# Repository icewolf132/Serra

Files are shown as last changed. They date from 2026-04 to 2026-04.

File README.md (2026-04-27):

# Serra domotica

Sistema di controllo automatizzato per la gestione di una serra che segue la [traccia della Gara Nazionale di Elettronica del 2023](https://github.com/icewolf132/Serra/blob/main/documentazione/2023%20Traccia%20GnE%202023.pdf).

---

## Contenuti del repository

* `schemi/` – schemi elettrici, PCB e partlist
* `firmware/` – codice sorgente per i microcontrollori PIC
* `documentazione/` – documentazione

---

## Diagramma 

[diagramma_progetto](https://github.com/icewolf132/Serra/blob/main/documentazione/foto/diagramma_progetto.png)

---

### Autore del progetto

* William Landolfi

---

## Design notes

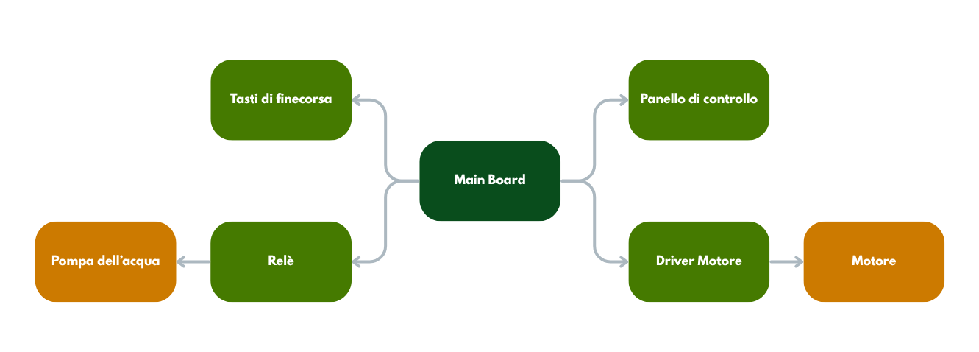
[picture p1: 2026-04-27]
documentazione/foto/diagramma_progetto.png

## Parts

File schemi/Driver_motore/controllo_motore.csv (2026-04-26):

Reference | Qty | Value | DNP | Exclude from BOM | Exclude from Board | Footprint | Datasheet
C1,C3 | 2 | 100nF |  |  |  |  | ~
C2 | 1 | 0,22uF |  |  |  |  | ~
C4 | 1 | 0,1uF |  |  |  |  | ~
D1 | 1 | 1N4007 |  |  |  | Diode_THT:D_DO-41_SOD81_P10.16mm_Horizontal | http://www.vishay.com/docs/88503/1n4001.pdf
J1 | 1 | PICKIT |  |  |  | Connector_PinSocket_2.54mm:PinSocket_1x06_P2.54mm_Vertical | ~
J2 | 1 | Motore |  |  |  | Connector_PinSocket_2.54mm:PinSocket_1x06_P2.54mm_Vertical | ~
J3 | 1 | Power |  |  |  | TerminalBlock:TerminalBlock_MaiXu_MX126-5.0-02P_1x02_P5.00mm | ~
J4 | 1 | Conn |  |  |  | Connector_PinSocket_2.54mm:PinSocket_1x05_P2.54mm_Vertical | ~
R4,R5,R6 | 3 | 470 |  |  |  |  | ~
U1 | 1 | L298N |  |  |  | Package_TO_SOT_THT:TO-220-15_P2.54x5.08mm_StaggerOdd_Lead4.58mm_Vertical | http://www.st.com/st-web-ui/static/active/en/resource/technical/document/datasheet/CD00000240.pdf
U2 | 1 | PIC16F88-IP |  |  |  | Package_DIP:DIP-18_W7.62mm_LongPads | http://ww1.microchip.com/downloads/en/DeviceDoc/30487D.pdf
U3 | 1 | LM7805_TO220 |  |  |  | Package_TO_SOT_THT:TO-220-3_Vertical | https://www.onsemi.cn/PowerSolutions/document/MC7800-D.PDF

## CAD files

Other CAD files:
firmware/driver_motore.X/dist/default/production/serra2.X.production.obj

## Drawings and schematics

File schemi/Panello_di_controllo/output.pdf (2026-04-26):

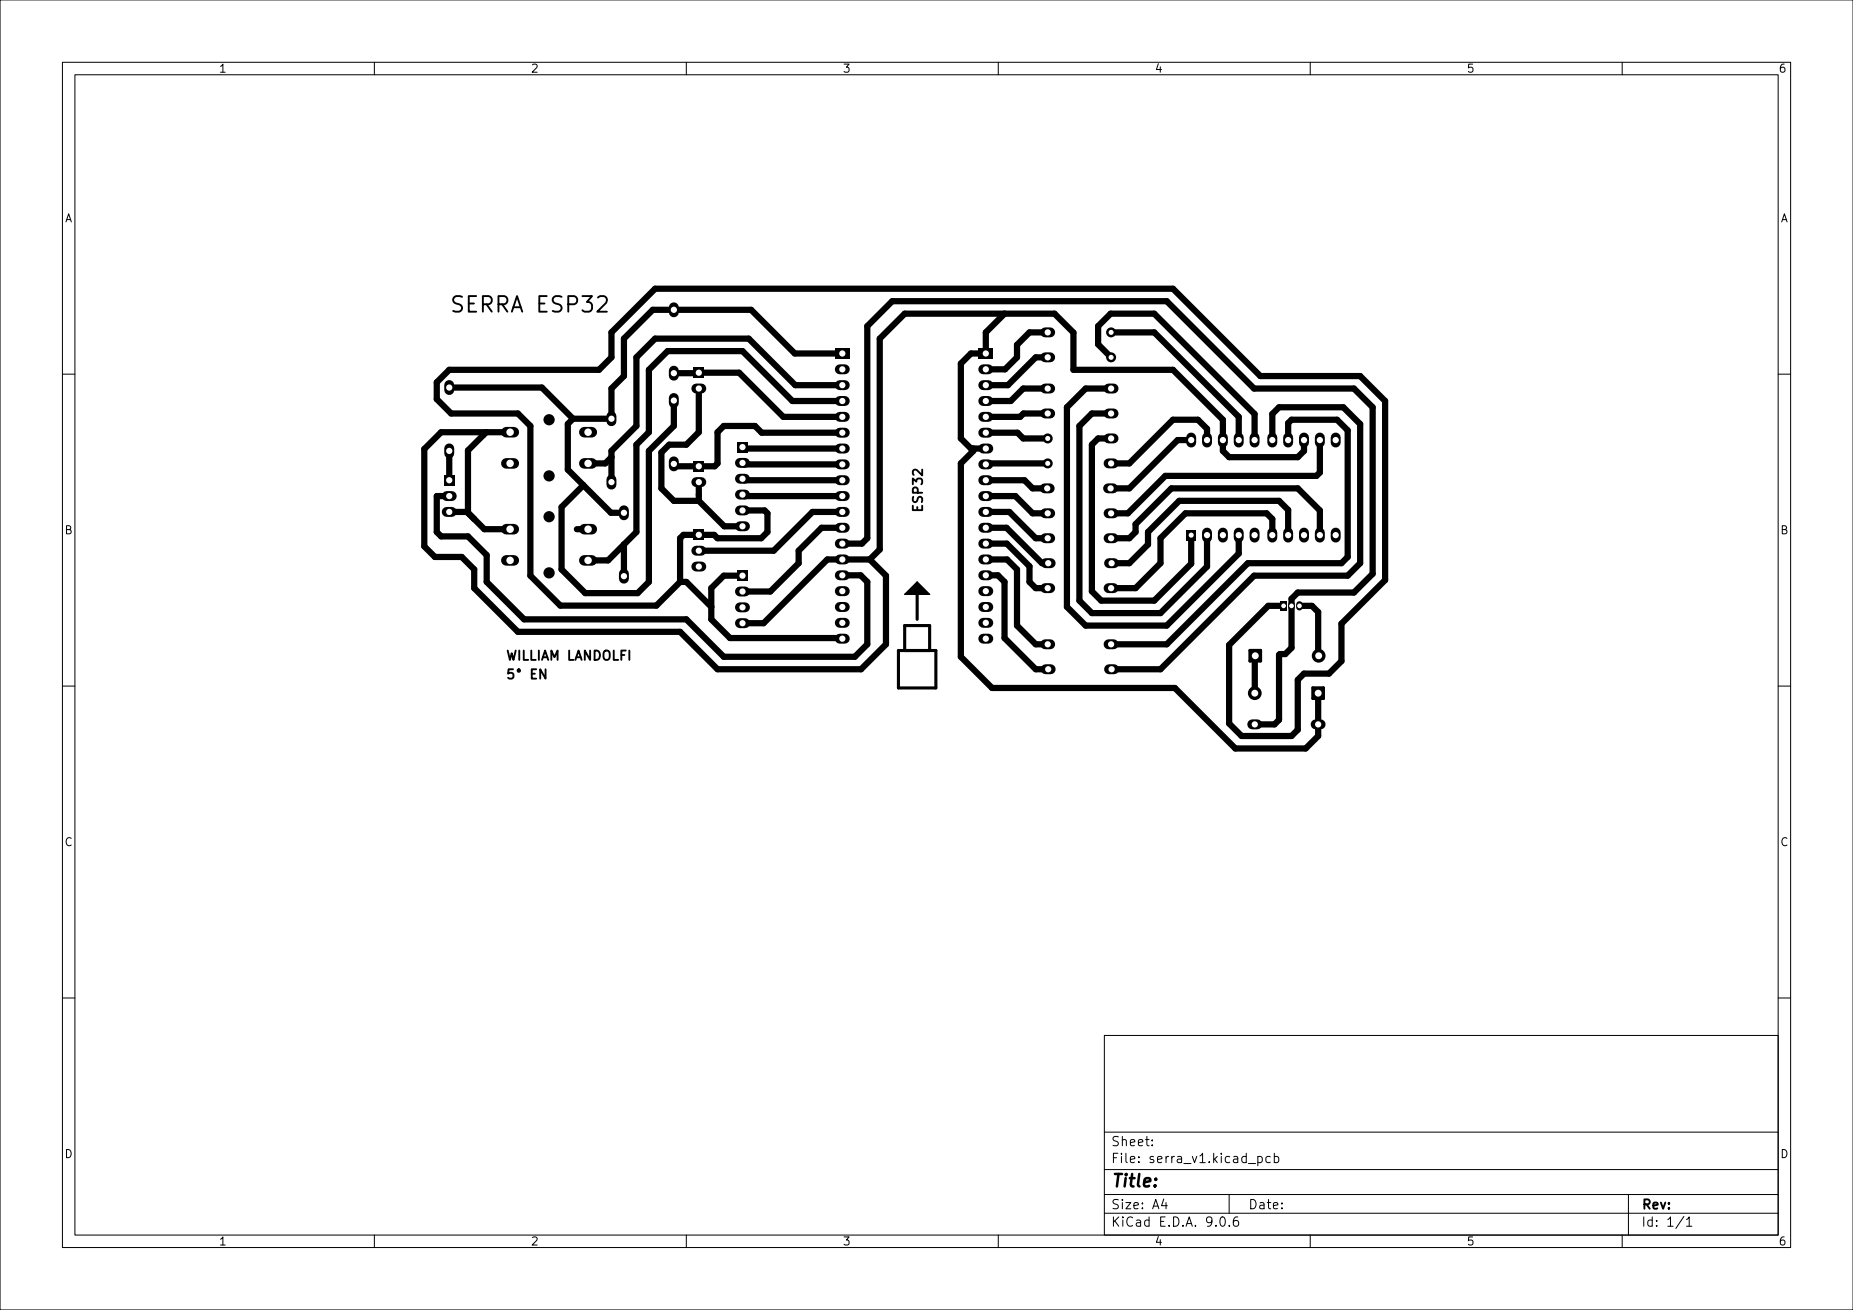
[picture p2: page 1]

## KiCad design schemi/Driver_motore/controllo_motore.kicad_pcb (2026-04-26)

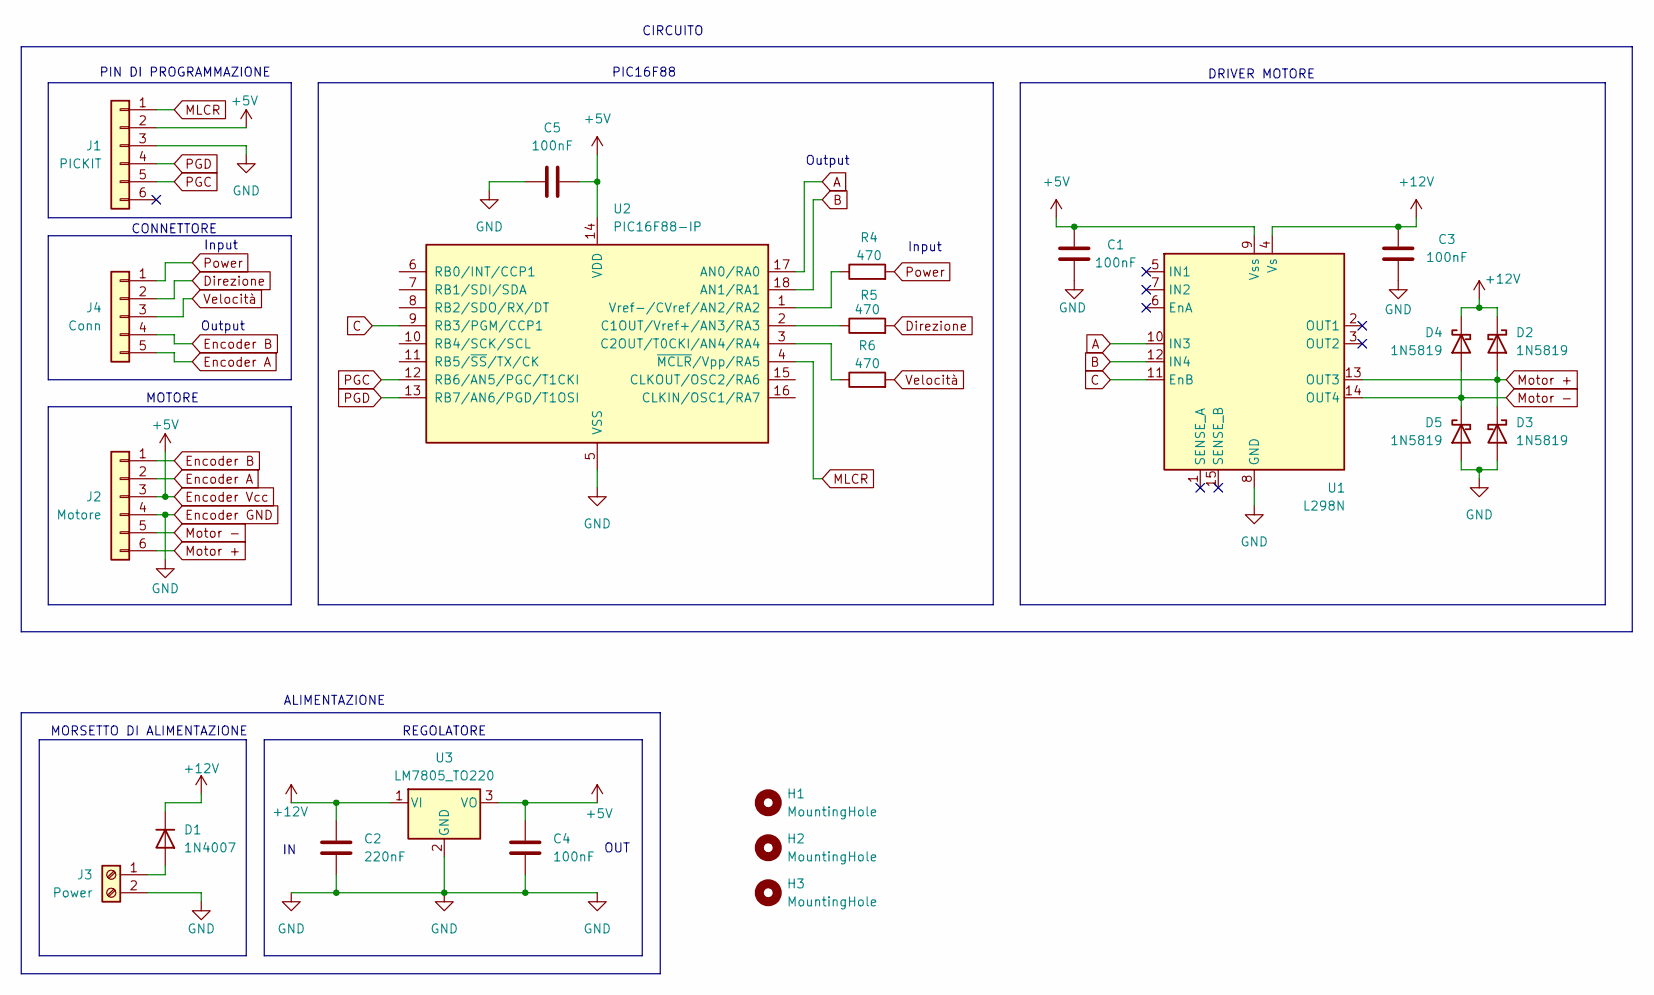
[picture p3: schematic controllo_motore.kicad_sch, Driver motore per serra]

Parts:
C1, C3, C4, C5: 100nF; C_Disc_D4.7mm_W2.5mm_P5.00mm
C2: 220nF; C_Disc_D4.7mm_W2.5mm_P5.00mm
D1: 1N4007; D_DO-41_SOD81_P10.16mm_Horizontal
D2, D3, D4, D5: 1N5819; D_DO-41_SOD81_P10.16mm_Horizontal
H1, H2, H3: MountingHole; MountingHole_3.2mm_M3_DIN965_Pad_TopBottom
J1: PICKIT; PinSocket_1x06_P2.54mm_Vertical
J2: Motore; PinSocket_1x06_P2.54mm_Vertical
J3: Power; TerminalBlock_MaiXu_MX126-5.0-02P_1x02_P5.00mm
J4: Conn; PinSocket_1x05_P2.54mm_Vertical
R4, R5, R6: 470; R_Axial_DIN0207_L6.3mm_D2.5mm_P10.16mm_Horizontal
U1: L298N; TO-220-15_P2.54x5.08mm_StaggerOdd_Lead4.58mm_Vertical
U2: PIC16F88-IP; DIP-18_W7.62mm_LongPads
U3: LM7805_TO220; TO-220-3_Vertical

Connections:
+12V: C2.1, C3.2, D1.1 (K), D2.1 (K), D4.1 (K), U1.4 (Vs), U3.1 (VI)
A: U1.10 (IN3), U2.17 (AN0/RA0)
B: U1.12 (IN4), U2.18 (AN1/RA1)
C: U1.11 (EnB), U2.9 (RB3/PGM/CCP1)
Direzione: J4.2, R5.2
Encoder A: J2.2, J4.5
Encoder B: J2.1, J4.4
Encoder GND: C1.1, C2.2, C3.1, C4.2, C5.1, D3.2 (A), D5.2 (A), J1.3, J2.4, J3.2, U1.8 (GND), U2.5 (VSS), U3.2 (GND)
Encoder Vcc: C1.2, C4.1, C5.2, J1.2, J2.3, U1.9 (Vss), U2.14 (VDD), U3.3 (VO)
MLCR: J1.1, U2.4 (~MCLR/Vpp/RA5)
Motor +: D2.2 (A), D3.1 (K), J2.6, U1.13 (OUT3)
Motor -: D4.2 (A), D5.1 (K), J2.5, U1.14 (OUT4)
unnamed: D1.2 (A), J3.1
unnamed: R5.1, U2.2 (C1OUT/Vref+/AN3/RA3)
unnamed: R6.1, U2.3 (C2OUT/T0CKI/AN4/RA4)
unnamed: R4.1, U2.1 (Vref-/CVref/AN2/RA2)
PGC: J1.5, U2.12 (RB6/AN5/PGC/T1CKI)
PGD: J1.4, U2.13 (RB7/AN6/PGD/T1OSI)
Power: J4.1, R4.2
Velocità: J4.3, R6.2

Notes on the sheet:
PIC16F88
ALIMENTAZIONE
Input
Output
MOTORE
OUT
REGOLATORE
DRIVER MOTORE
CIRCUITO
PIN DI PROGRAMMAZIONE
CONNETTORE
MORSETTO DI ALIMENTAZIONE

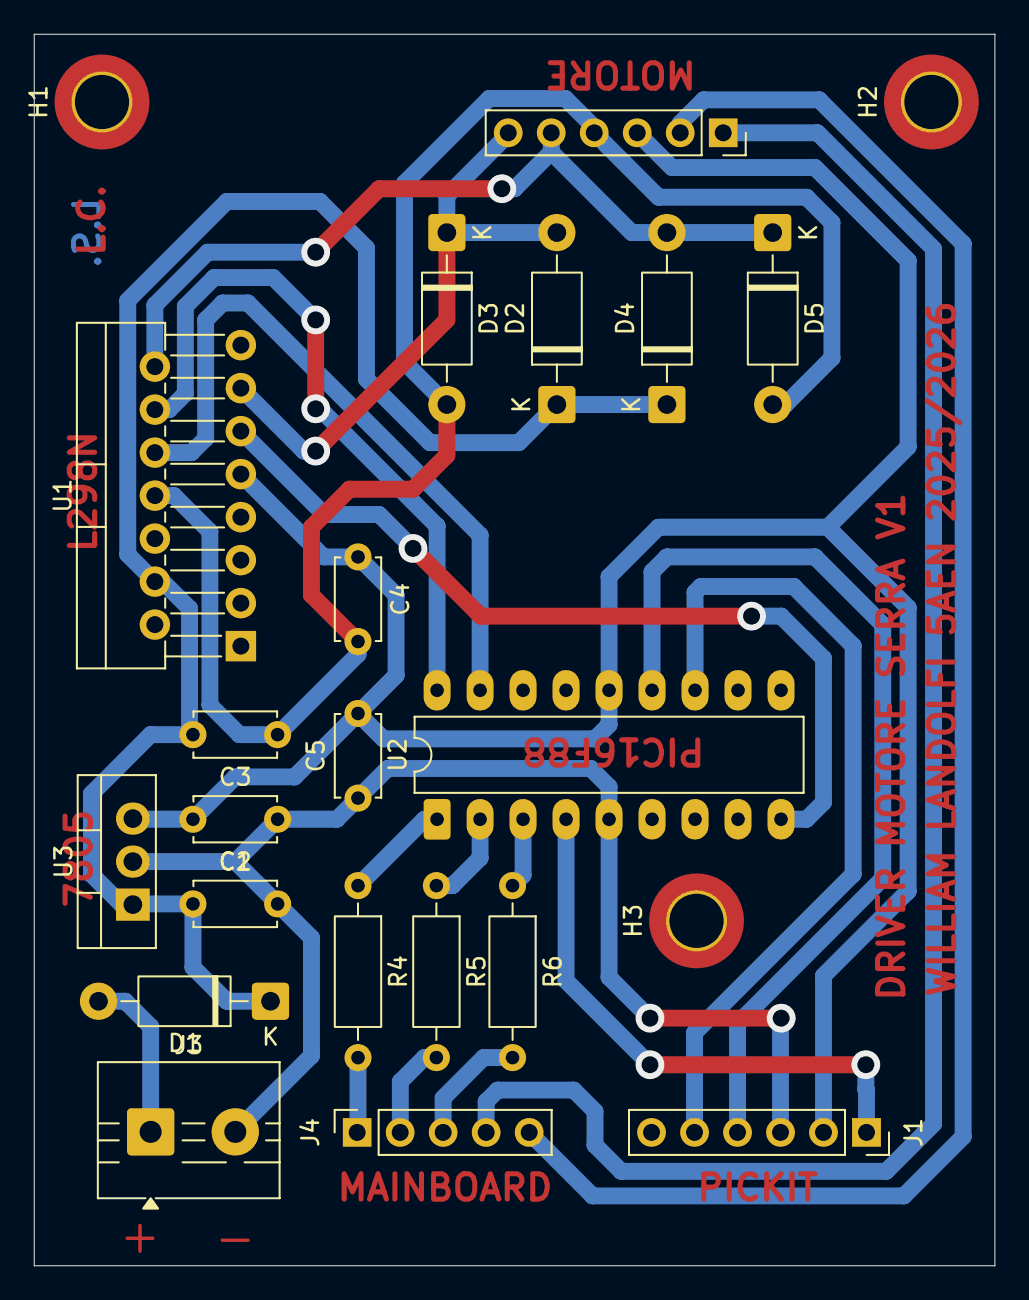
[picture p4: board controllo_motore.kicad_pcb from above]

Board: 2 copper layers, 56.8 x 72.8 mm, 23 parts (0 on the bottom side), 20 nets.

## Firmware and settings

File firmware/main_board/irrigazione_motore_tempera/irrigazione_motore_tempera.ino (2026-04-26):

#include <Stepper.h>
#include <ESP32Servo.h>


/************ DEFINE *******************************/
//define per la gestione semplificata del motore
#define START 1
#define STOP 0

#define AVANTI 1
#define DIETRO 0

#define VELOCE 1
#define LENTO 0

#define WET 1
#define DRY 0
/********************************************************/



/************* ASSEGNAZIONI COSTANTI ******************************************************************************************/
//assegnazione pin irrigazione
const int pin_power=27, pin_dir=26, pin_vel=25, pin_acqua=33, pin_STOP=32, pin_START=35, pin_MODO=34, pin_FC1=39, pin_FC2=36;

//assegnazione pin driver motore
const int pin_IN1=19, pin_IN3=18, pin_IN2=5, pin_IN4=17;

//assegnazioni variabili per la libreria Stepper.h
const int stepsPerRevolution = 2048;  //number of steps per revolution



const int PIN_FINESTRE = 22, PIN_VENTOLE = 23, pin_Relè=21, pin_servo=16;


// Costanti per il sensore (locali nella funzione sarebbe meglio, ma così eviti di ricalcolarle)
const int ADC_ZERO_GRADI = 1070;
const float ADC_PER_GRADO = (4095/3.30)*0.01;

/******************************************************************************************************************************/



/*********** COMANDI FISSI PER FUNZIONI E LIBRERIE *****************/
// inizializzazione timer
hw_timer_t *timer = NULL;
volatile bool timer_scaduto = false;  // DEVE essere globale e volatile (usata nell'interrupt)

// inizializzazione servo per ventole
Servo MyServo;

// inizializzazione libreria Stepper.h per motore passo passo
Stepper myStepper(2048, 19, 5 , 18, 17);
/*******************************************************************/



/************ FUNZIONI SECONDARIE ************************************/
//funzione per il timer dello stop
void IRAM_ATTR onTimer()
{
  timer_scaduto = true; //quando il timer della ventola arriva a 3s imposto il flag a vero
  //quando il timer del tasto di stop scade arrivo il flag (meglio usare due timer diversi)
}

//setup per la parte della temperatura
void setupTemp()
{
  pinMode(PIN_FINESTRE, OUTPUT);
  pinMode(PIN_VENTOLE, OUTPUT);
  pinMode(pin_Relè, OUTPUT);
  
  digitalWrite(PIN_FINESTRE, LOW);
  digitalWrite(PIN_VENTOLE, LOW);
  digitalWrite(pin_Relè, LOW);
}

//setup per la parte dell'irrigazione
void setup_Irrigazione()
{
  //Output
  pinMode(pin_power,OUTPUT);
  pinMode(pin_dir,OUTPUT);
  pinMode(pin_vel,OUTPUT);

  pinMode(pin_acqua,OUTPUT);

  //Input
  pinMode(pin_FC1,INPUT);
  pinMode(pin_FC2,INPUT);

  pinMode(pin_START,INPUT);
  pinMode(pin_STOP,INPUT);
  pinMode(pin_MODO, INPUT);
}

//funzione per il sensore di temperatura per scrivere la temperatura su una variabile
int sensoreTemp() 
{
  int somma = 0;
  for (int i = 0; i < 10; i++) 
  {
    somma += analogRead(4);
    delay(10);
  }
  
  int temp = somma / 10;
  temp = temp - ADC_ZERO_GRADI;
  temp = temp / ADC_PER_GRADO;
  
  return temp;
}

//funzione dipendente da irrigazione per semplificare la gestione della barra
void barra (int power, int direzione, int velocità, int acqua)
{
  if (power == START) 
  {
    digitalWrite(pin_power, 1);

    if ( direzione == AVANTI)
    {
      digitalWrite(pin_dir, 1);
      myStepper.step(1); Serial.print("avanti ");//manda il motore verso in avanti
    }
    else 
    {
      digitalWrite(pin_dir, 0);
      myStepper.step(-1); Serial.print("dietro ");//manda il motore indietro
    }

    if (velocità == VELOCE) digitalWrite(pin_vel, 1);
    else digitalWrite(pin_vel, 0);

    if (acqua == WET) digitalWrite(pin_acqua, 1);
    else digitalWrite(pin_acqua, 0);
  }
  else
  {
    digitalWrite(pin_power, 0);
    digitalWrite(pin_vel, 0);
    digitalWrite(pin_dir, 0);
    digitalWrite(pin_acqua, 0);
  }
}
/*************************************************************************/



/************** FUNZIONI PRINCIPALI ******************************************************************************/
//funzione principale d'irrigazione
void Irrigazione()
{
  static int stato_irrigazione=0, stato_irrigazione_precedente;
  Serial.println(stato_irrigazione);
/*
  if(digitalRead(pin_STOP) == 1) 
  {
    stato_irrigazione_precedente = stato_irrigazione; //mi salvo a che punto stava l'irrigazione
    stato_irrigazione=10; //interrupt virtuale 
  }
*/

  switch (stato_irrigazione)
  {
    case 0: //tutto spendo
      barra(STOP, DIETRO, LENTO, DRY);
      if(digitalRead(pin_START) == 0) stato_irrigazione=1; //se premo start
    break;

    case 1: //mando la barra all'inizio
      barra(START, DIETRO, VELOCE, DRY);
      if(digitalRead(pin_FC1) == 1) stato_irrigazione=2; //se è arrivato all'inizio
    break;

    case 2: //mando la barra alla fine
      barra(START, AVANTI, LENTO, WET); 
      if(digitalRead(pin_FC2) == 1) stato_irrigazione=3;
    break;

    case 3: //controllo il modo di irrigazione
      if (digitalRead(pin_MODO) == 1) stato_irrigazione=4; //se Modo 0 (aperto) vai allo stato 4
      else stato_irrigazione=5; //se Modo 1 (chiuso) vai allo stato 5
    break;

    case 4: //è stato selezionato ritorno veloce senza irrigazione
      barra(START, DIETRO, VELOCE, DRY);
      if(digitalRead(pin_FC1) == 1) stato_irrigazione=0;
    break;
    

    case 5: //è stato selezionata ritorno lento con irrigazione
      barra (START, DIETRO, LENTO, WET);
      if(digitalRead(pin_FC1) == 1) stato_irrigazione=0;
    break;

    /*
    case 10:
      // Ferma tutto
      stato_irrigazione = stato_irrigazione_precedente;   //memorizza lo stato in cui stava l'irrigazione
      barra(STOP, DIETRO, LENTO, DRY);                    // blocca la barra

      // Aspetto 5 secondi
      timerWrite(timer_STOP, 0);  //Azzera il contatore a 0
      flag_STOP = false;          //reseto il flag per sicurezza

      // Se premo START il ciclo riprende da dov'era
      if(digitalRead(pin_START)==0) //se premo il tasto start
      {
        stato_irrigazione = stato_irrigazione_precedente;
      }

      // Se sono passati 5 secondi e lo stop è ancora premuto
      if(flag_STOP == true)
      {
        flag_STOP = false;    //resetta il flag del timer di stop
        stato_irrigazione=4;  //vai allo stato 4
      }
    break;
    */
  }
}

void Temperatura(void)
{
  static int stato = 0;  // static: mantiene il valore tra le chiamate,
  static bool timer_avviato = false;  // static: mantiene il valore tra le chiamate
  
  int temp = sensoreTemp();
  
  Serial.print("Temp: ");
  Serial.print(temp);
  Serial.print("°C | Stato: ");
  Serial.print(stato);
  
  switch(stato)
  {
    case 0: // stato iniziale dove è tutto spento
      digitalWrite(PIN_FINESTRE, LOW);
      MyServo.write(110);
      digitalWrite(PIN_VENTOLE, LOW);
      digitalWrite(pin_Relè, LOW);

      Serial.println(" | Finestre=0, Ventole=0");
      
      if(temp > 23) {
        Serial.println(">>> Passo a stato 1");
        stato = 1;
        timer_avviato = false;
        timer_scaduto = false;
      }
      break;
      
    case 1: // accende finestre e avvia timer
      digitalWrite(PIN_FINESTRE, HIGH);
      MyServo.write(0);
      digitalWrite(PIN_VENTOLE, LOW);
      digitalWrite(pin_Relè, LO2W);

      Serial.print(" | Finestre=1, Ventole=0");
      
      if (!timer_avviato) {
        // Ricrea il timer
        if (timer != NULL) {
          timerEnd(timer);
        }
        timer = timerBegin(1000000);
        timerAttachInterrupt(timer, &onTimer);
        timerAlarm(timer, 3000000, false, 0);
        
        timer_scaduto = false;
        timer_avviato = true;
        Serial.println(" | >>> TIMER AVVIATO");
      } else {
        Serial.println(" | Timer in corso...");
      }
      
      if (timer_scaduto) {
        Serial.println(">>> 3 SECONDI! Passo a stato 2");
        stato = 2;
        timer_avviato = false;
      }
      break;
      
    case 2: // accende anche ventole
      digitalWrite(PIN_FINESTRE, HIGH);
      MyServo.write(0);
      digitalWrite(PIN_VENTOLE, HIGH);
      digitalWrite(pin_Relè, HIGH);

      Serial.println(" | Finestre=1, Ventole=1");
      
      if(temp < 22) {
        Serial.println(">>> Torno a stato 0");
        stato = 0;
        if (timer != NULL) {
          timerEnd(timer);
          timer = NULL;
        }
      }
      break;
  }
}
/*************************************************************************************/



/****** FUNZIONI OBBLIGATORIE *****************/
void setup() 
{
  MyServo.attach(pin_servo);
  MyServo.write(0);

  Serial.begin(9600);
  setupTemp();
  myStepper.setSpeed(17);
  setup_Irrigazione();

  timer = timerBegin(3000000);
  timerAttachInterrupt(timer, &onTimer);
  timerAlarm(timer, 3000000, true, 0);
}

void loop() 
{
  Irrigazione();
  Temperatura();
}

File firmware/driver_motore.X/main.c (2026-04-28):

/*
 * File:   main.c
 * Author: William Landolfi
 *
 * Created on 28 aprile 2026, 21.38
 */

#include "header.h"

#define POWER RA2
#define DIR RA3
#define VEL RA7
  
void dir_out (int input)
{
    switch (input)
    {
        case 0: // indietro
            RA0 = 0;
            RA1 = 1;
            break;

        case 1: // avanti
            RA0 = 1;
            RA1 = 0;
            break;
    }
}

void vel_out (int speed)
{
    switch (speed)
    {
        case 0: // lento
            RB3 = 1;
            __delay_ms(500);
            RB3 = 0;
            __delay_ms(500);
            break;

        case 1: // veloce
            RB3 = 1;
            break;
    }
}

void main(void)
{
    OSCCON = 0b01110000; // 8 MHz interno
    ANSEL = 0x00;  // Tutti i pin digitali

    TRISA = 0b00011100; // dichiaro ingressi e uscite nel registo A
    PORTA = 0b00000000; // imposto tutte le uscite a 0 logico

    TRISB = 0b00000000; 
    PORTB = 0b00000000;

    while(1) 
    {
        if (POWER == 1)     //controlla lo stato de
        {
            // 4 modalità possibili
            if(DIR == 0 && VEL == 0) // se indietro lento
            { 
                dir_out(0);
                vel_out(0);
            }

            else if(DIR == 0 && VEL == 1) // se indietro veloce
            { 
                dir_out(0);
                vel_out(1);
            }

            else if(DIR == 1 && VEL == 0) // se avanti lento
            { 
                dir_out(1);
                vel_out(0);
            }

            else if(DIR == 1 && VEL == 1) // se avanti veloce
            { 
                dir_out(1);
                vel_out(1);
            }
        }
    }
    return;
}

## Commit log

2026-01-12 sistemato il programma motore
2026-01-13 creato il programma d'irrigazione con implementazione motore
2026-04-26 aggiundo il pcd del driver motore
    [controllo_motore.csv, controllo_motore.kicad_pcb, controllo_motore.kicad_sch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]
2026-04-26 migliorato il main del driver motore
2026-04-27 sistemato le cartelle
    [controllo_motore.csv, controllo_motore.kicad_pcb, controllo_motore.kicad_sch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]
2026-05-31 update main board
2026-06-20 aggiunto la visualizzazione al panello di controllo
